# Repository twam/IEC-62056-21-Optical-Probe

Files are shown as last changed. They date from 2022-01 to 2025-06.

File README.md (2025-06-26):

IEC-62056-21-Optical-Probe
===

Optical probe for reading out power meters supporting the [IEC 62056-21](https://www.ungelesen.net/protagWork/media/downloads/solar-steuerung/iec62056-21%7Bed1.0%7Den_.pdf) standard via USB.

Infrared part is based on https://wiki.volkszaehler.org/hardware/controllers/ir-schreib-lesekopf-ttl-ausgang.

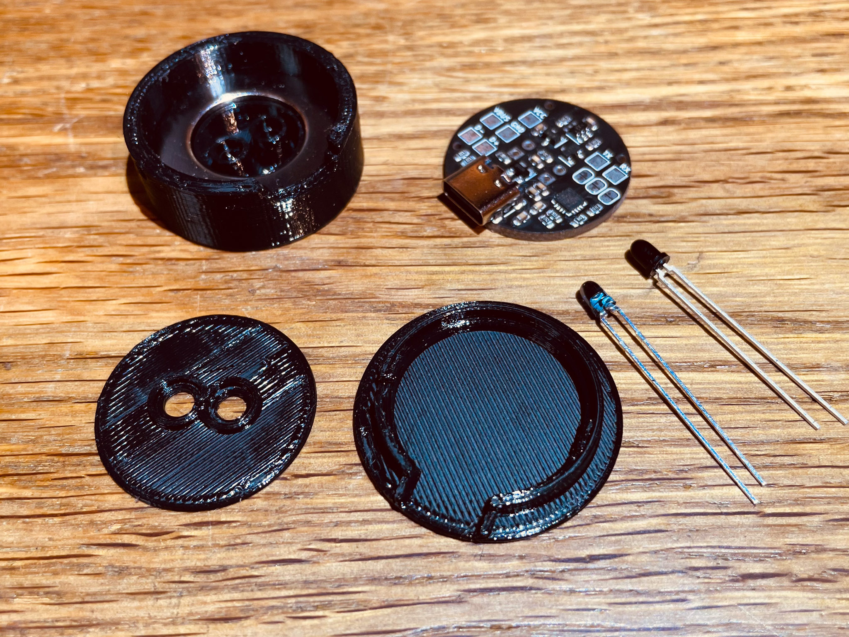
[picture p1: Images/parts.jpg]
PCB and case parts


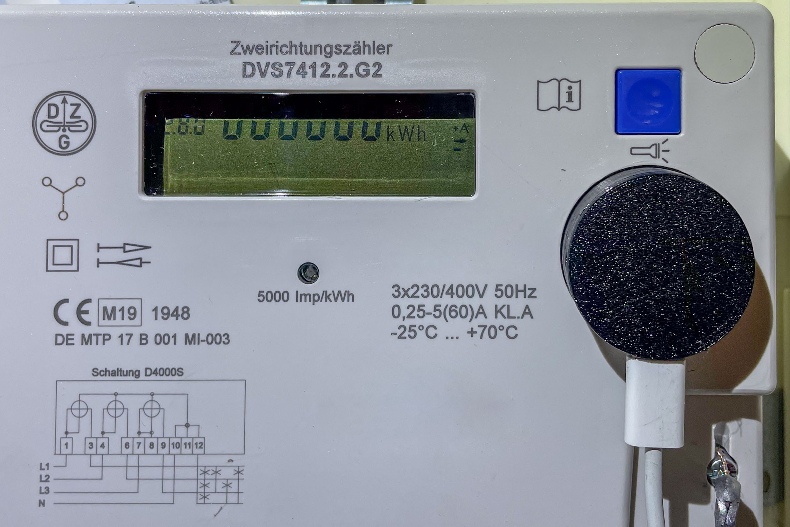
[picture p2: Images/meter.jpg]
Probe mounted on a meter


For the case a ring magnet with Ø 26,75/16 mm and 5 mm height is required, e.g. [this one](https://www.supermagnete.de/eng/ring-magnets-neodymium/ring-magnet-26.75mm-16mm-5mm_R-27-16-05-N).

### JLCPCB

PCBs can be ordered fully-assembled (besides the IR-LED and Photodiode) from [JLCPCB](https://jlcpcb.com/DDE). Required files are
[IEC-62056-21-Optical-Probe_cpl_jlc.csv](Gerber/IEC-62056-21-Optical-Probe_cpl_jlc.csv), [IEC-62056-21-Optical-Probe_bom_jlc.csv](Gerber/IEC-62056-21-Optical-Probe_bom_jlc.csv) and
[IEC-62056-21-Optical-Probe.zip](IEC-62056-21-Optical-Probe.zip).

## License

[][cc-by-sa]

This work is licensed under a [Creative Commons Attribution-NonCommercial-ShareAlike 4.0 International License][cc-by-sa].

[][cc-by-sa]

[cc-by-sa]: http://creativecommons.org/licenses/by-nc-sa/4.0/
[cc-by-sa-image]: https://licensebuttons.net/l/by-nc-sa/4.0/88x31.png
[cc-by-sa-shield]: https://img.shields.io/badge/License-CC%20BY--NC--SA%204.0-lightgrey.svg

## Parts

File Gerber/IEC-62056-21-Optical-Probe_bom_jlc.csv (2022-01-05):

Comment | Designator | Footprint | LCSC Part #
100n/50V | C1,C2,C3,C5,C6 | C_0603_1608Metric | C14663
4u7/16V | C4,C7 | C_0603_1608Metric | C19666
SP0503BAHT | D1 | SOT-143 | C7074
USB_C_Receptacle_USB2.0 | J1 | USB_C_Receptacle_XKB_U262-16XN-4BVC11 | C165948
S8550 | Q2 | SOT-23 | C105432
S8050 | Q4 | SOT-23 | C2146
5k1 | R1,R2 | R_0603_1608Metric | C23186
24k | R4 | R_0603_1608Metric | C23352
47k | R5 | R_0603_1608Metric | C25819
1k | R7 | R_0603_1608Metric | C21190
10k | R12 | R_0603_1608Metric | C25804
180R | R13 | R_0603_1608Metric | C22828
13k | R14,R15,R16 | R_0603_1608Metric | C22797
CP2102N-Axx-xQFN20 | U2 | SiliconLabs_QFN-20-1EP_3x3mm_P0.5mm_EP1.8x1.8mm | C969913
74LVC2G17 | U3 | SC-74-6_1.5x2.9mm_P0.95mm | C513289

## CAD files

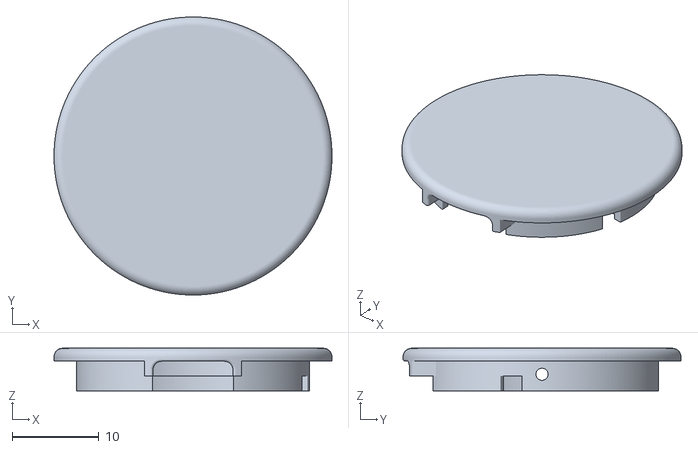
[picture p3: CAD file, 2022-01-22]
Case/Top.stl
32.0 x 32.0 x 4.90

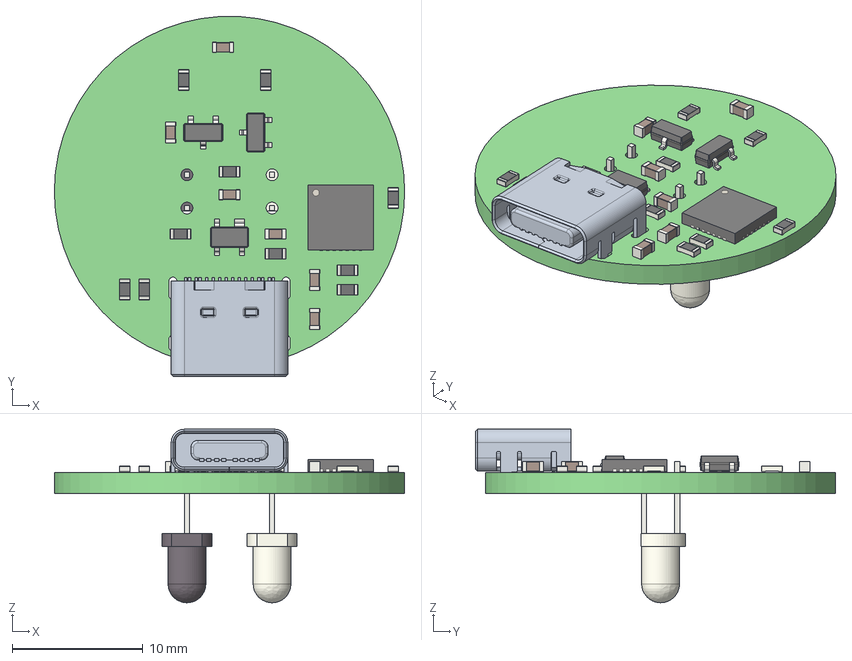
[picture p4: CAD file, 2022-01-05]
IEC-62056-21-Optical-Probe.step
26.8 x 27.5 x 13.3 mm
IEC-62056-21-Optical-Probe PCB

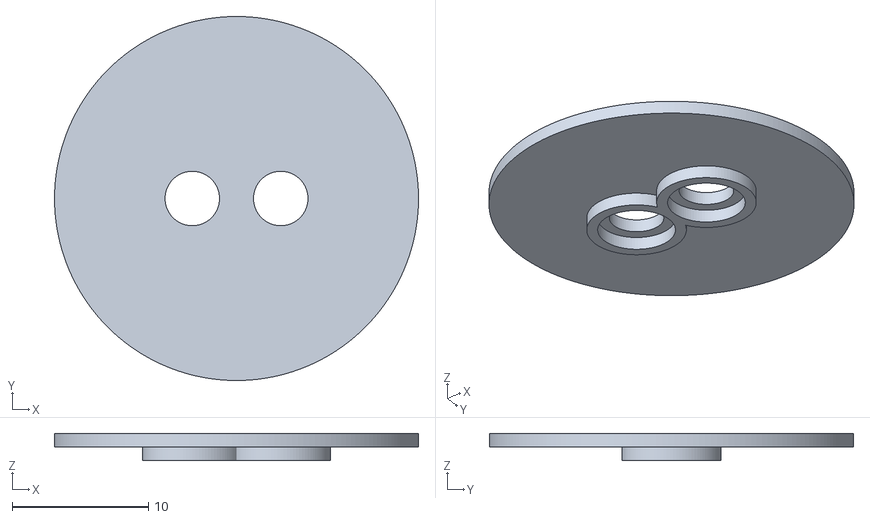
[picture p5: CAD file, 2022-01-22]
Case/Isolation.stl
26.7 x 26.7 x 2.00

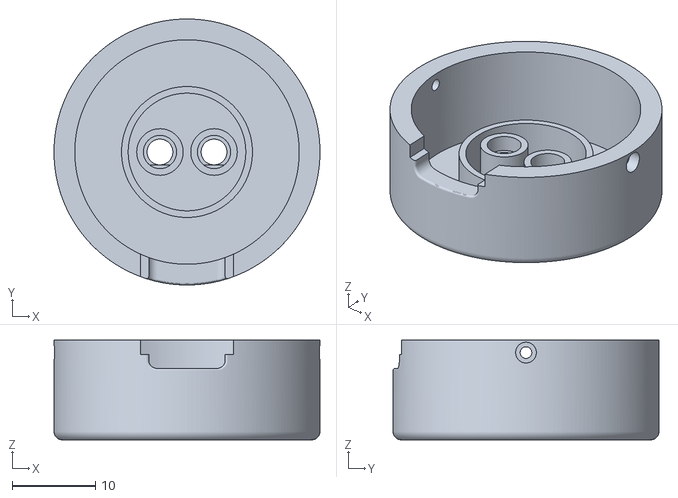
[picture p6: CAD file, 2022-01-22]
Case/Base.stl
32.0 x 32.0 x 12.0

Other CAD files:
Case/Case.f3d

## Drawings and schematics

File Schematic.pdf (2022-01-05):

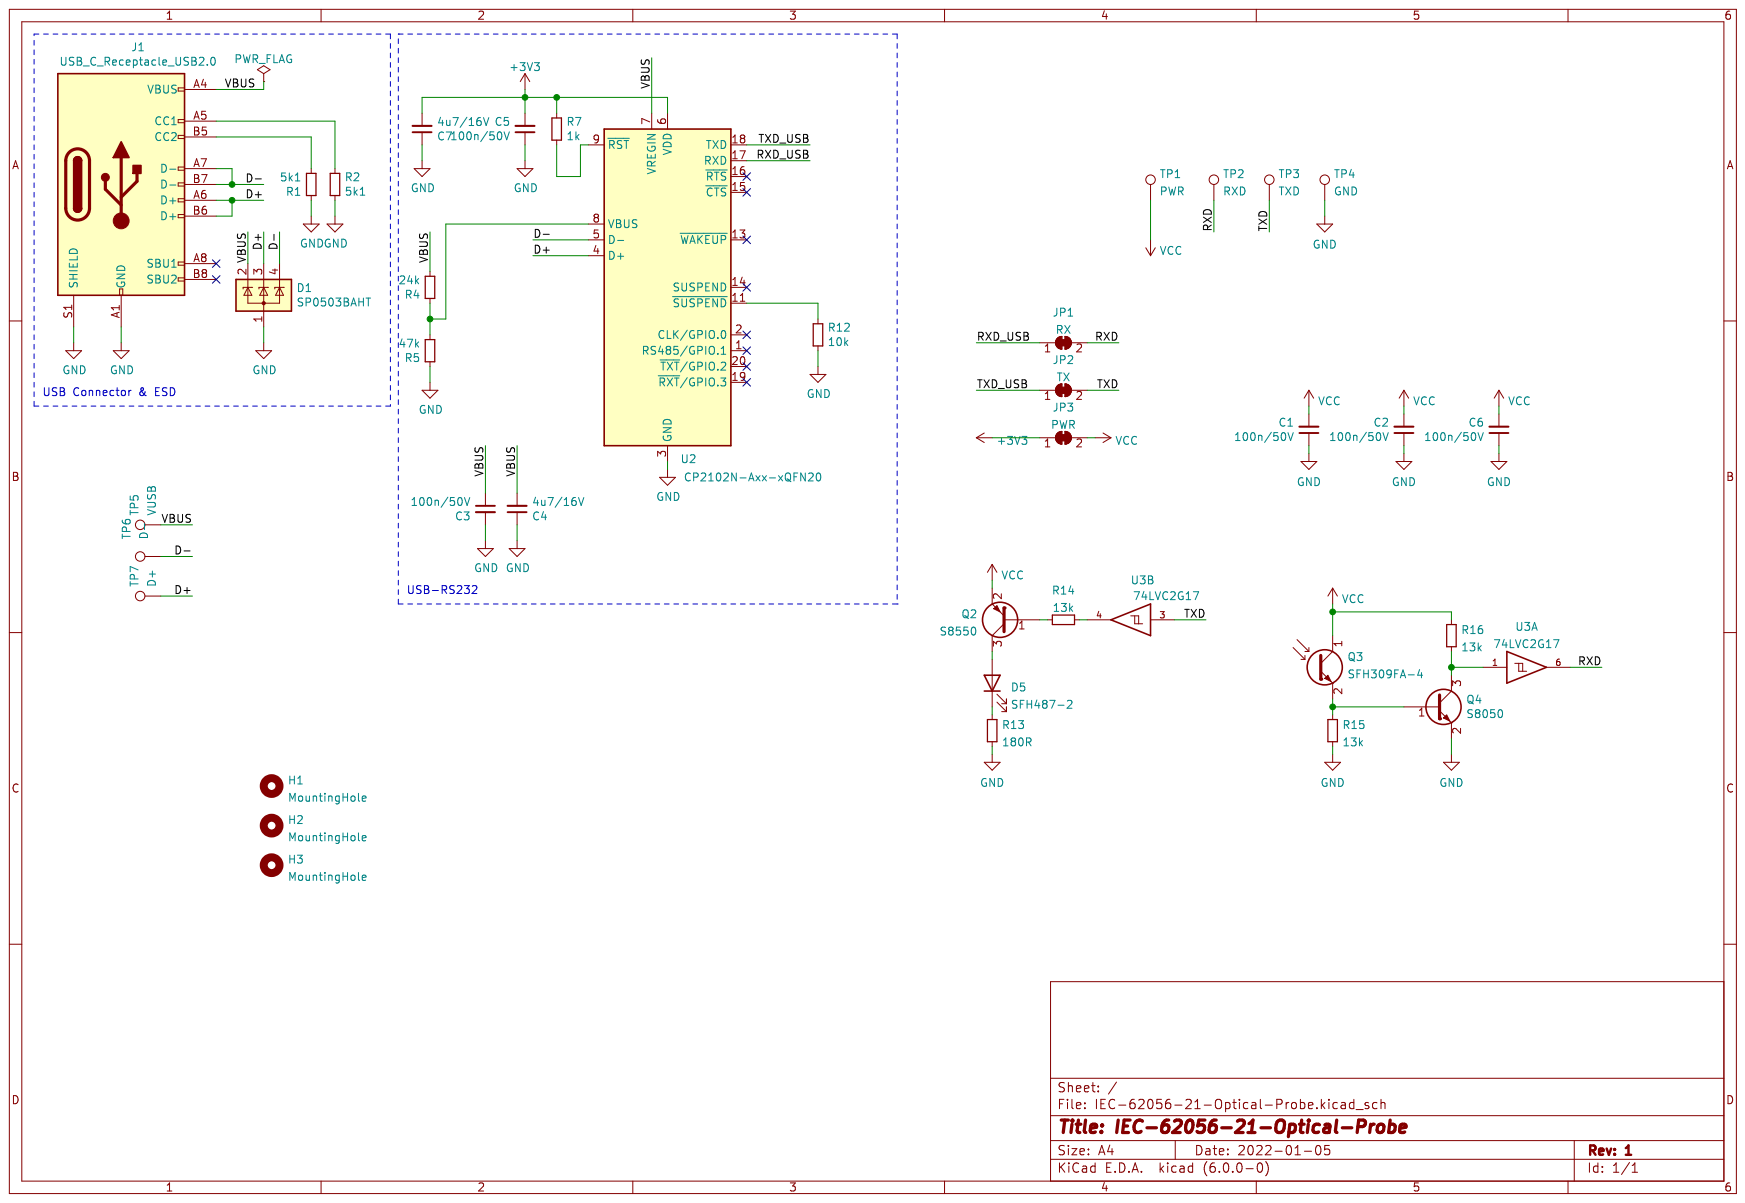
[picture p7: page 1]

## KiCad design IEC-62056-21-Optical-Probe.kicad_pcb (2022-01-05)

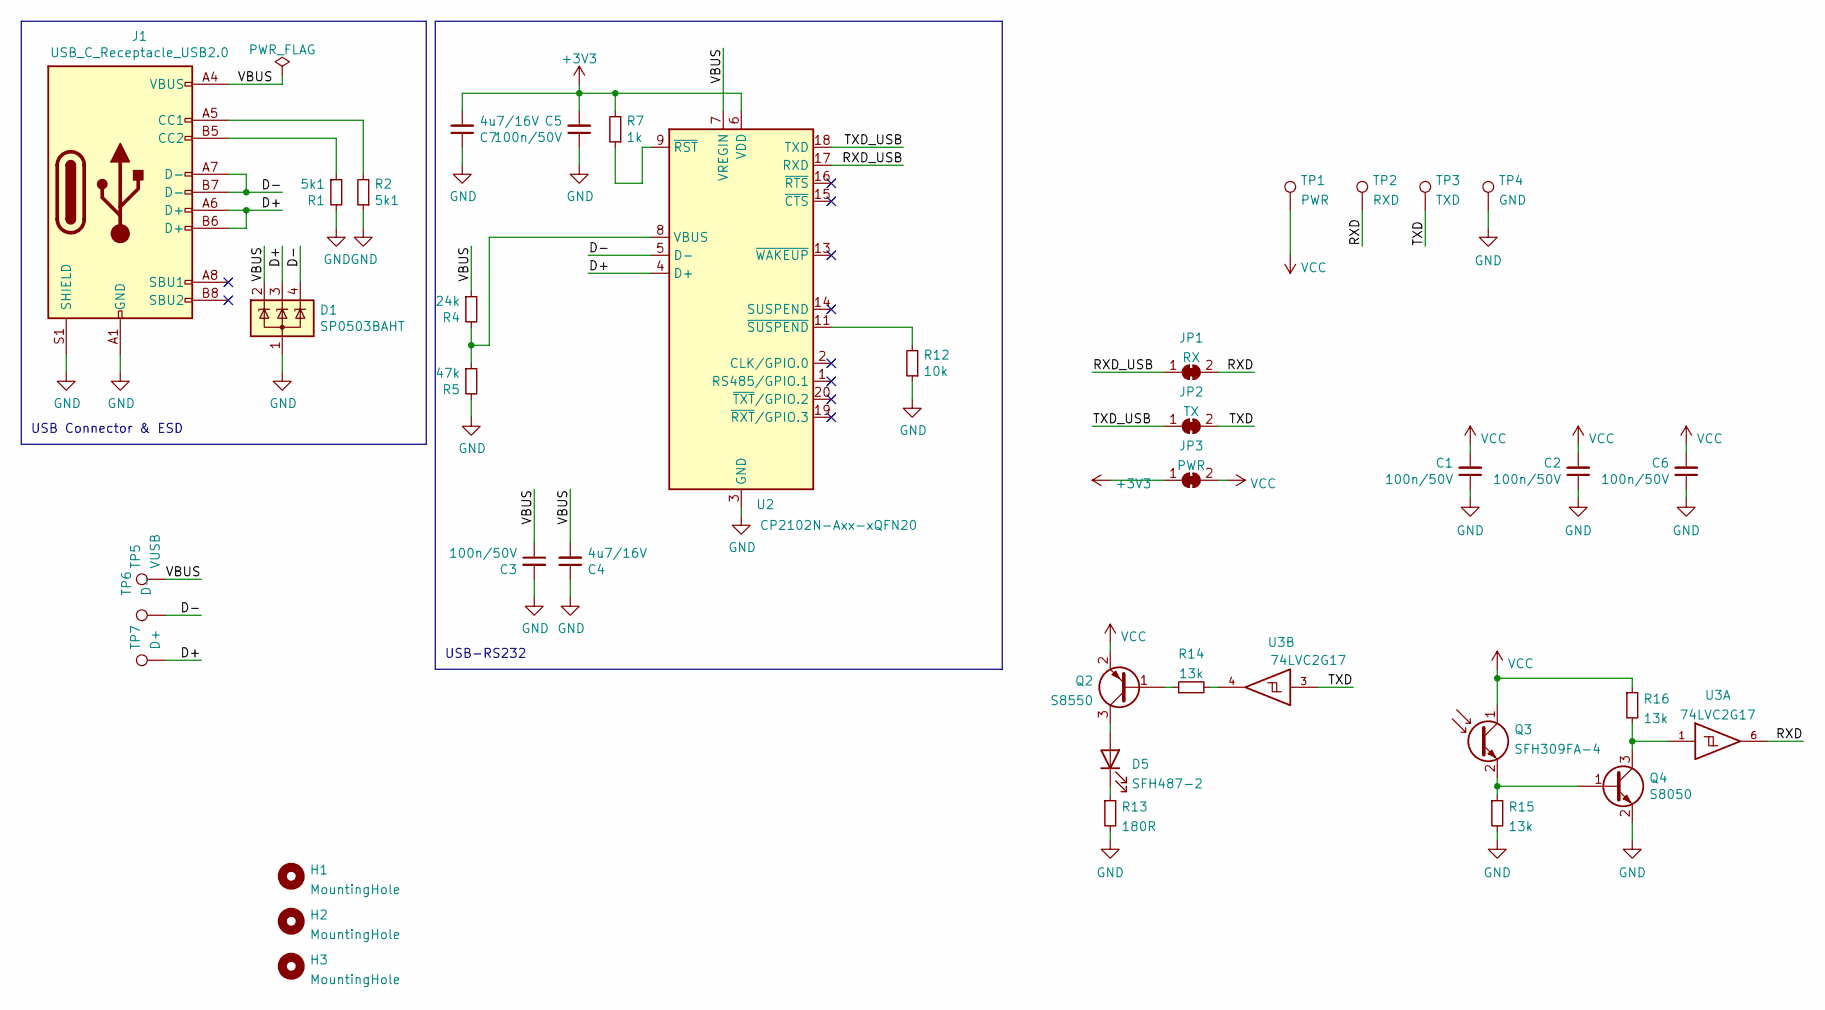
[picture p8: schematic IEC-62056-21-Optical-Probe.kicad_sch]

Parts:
C1, C2, C3, C5, C6: 100n/50V; C_0603_1608Metric; LCSC C14663
C4, C7: 4u7/16V; C_0603_1608Metric; LCSC C19666
D1: SP0503BAHT; SOT-143; LCSC C7074
D5: SFH487-2; LED_D3.0mm_IRBlack
H1, H2, H3: MountingHole; MountingHole_JLCPCB
J1: USB_C_Receptacle_USB2.0; USB_C_Receptacle_XKB_U262-16XN-4BVC11; LCSC C165948
JP1: RX; SolderJumper-2_P1.3mm_Bridged_RoundedPad1.0x1.5mm
JP2: TX; SolderJumper-2_P1.3mm_Bridged_RoundedPad1.0x1.5mm
JP3: PWR; SolderJumper-2_P1.3mm_Bridged_RoundedPad1.0x1.5mm
Q2: S8550; SOT-23; LCSC C105432
Q3: SFH309FA-4; LED_D3.0mm_Clear
Q4: S8050; SOT-23; LCSC C2146
R1, R2: 5k1; R_0603_1608Metric; LCSC C23186
R4: 24k; R_0603_1608Metric; LCSC C23352
R5: 47k; R_0603_1608Metric; LCSC C25819
R7: 1k; R_0603_1608Metric; LCSC C21190
R12: 10k; R_0603_1608Metric; LCSC C25804
R13: 180R; R_0603_1608Metric; LCSC C22828
R14, R15, R16: 13k; R_0603_1608Metric; LCSC C22797
TP1: PWR; TestPoint_Pad_2.0x2.0mm
TP2: RXD; TestPoint_Pad_2.0x2.0mm
TP3: TXD; TestPoint_Pad_2.0x2.0mm
TP4: GND; TestPoint_Pad_2.0x2.0mm
TP5: VUSB; TestPoint_Pad_2.0x2.0mm
TP6: D-; TestPoint_Pad_2.0x2.0mm
TP7: D+; TestPoint_Pad_2.0x2.0mm
U2: CP2102N-Axx-xQFN20; SiliconLabs_QFN-20-1EP_3x3mm_P0.5mm_EP1.8x1.8mm; LCSC C969913
U3: 74LVC2G17; SC-74-6_1.5x2.9mm_P0.95mm; LCSC C513289

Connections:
+3V3: C5.2, C7.2, JP3.1 (A), R7.2, U2.6 (VDD)
/D+: D1.3 (K), J1.A6 (D+), J1.B6 (D+), TP7.1, U2.4 (D+)
/D-: D1.4 (K), J1.A7 (D-), J1.B7 (D-), TP6.1, U2.5 (D-)
/RXD: JP1.2 (B), TP2.1, U3.6
/RXD_USB: JP1.1 (A), U2.17 (RXD)
/TXD: JP2.2 (B), TP3.1, U3.3
/TXD_USB: JP2.1 (A), U2.18 (TXD)
/VBUS: C3.1, C4.2, D1.2 (K), J1.A4 (VBUS), J1.A9 (VBUS), J1.B4 (VBUS), J1.B9 (VBUS), R4.1, TP5.1, U2.7 (VREGIN)
GND: C1.1, C2.1, C3.2, C4.1, C5.1, C6.1, C7.1, D1.1 (A), J1.A1 (GND), J1.A12 (GND), J1.B1 (GND), J1.B12 (GND), J1.S1 (SHIELD), Q4.2 (E), R1.2, R2.1, R5.2, R12.1, R13.2, R15.2, TP4.1, U2.3 (GND), U2.12 (GND), U2.21 (GND), U3.2 (GND)
unnamed: D5.1 (K), R13.1
unnamed: D5.2 (A), Q2.3 (C)
unnamed: J1.A5 (CC1), R2.2
unnamed: J1.B5 (CC2), R1.1
unnamed: Q2.1 (B), R14.1
unnamed: Q3.2 (E), Q4.1 (B), R15.1
unnamed: Q4.3 (C), R16.2, U3.1
unnamed: R4.2, R5.1, U2.8 (VBUS)
unnamed: R7.1, U2.9 (~RST)
unnamed: R12.2, U2.11 (~SUSPEND)
unnamed: R14.2, U3.4
VCC: C1.2, C2.2, C6.2, JP3.2 (B), Q2.2 (E), Q3.1 (C), R16.1, TP1.1, U3.5 (VCC)

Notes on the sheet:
USB Connector & ESD
USB-RS232

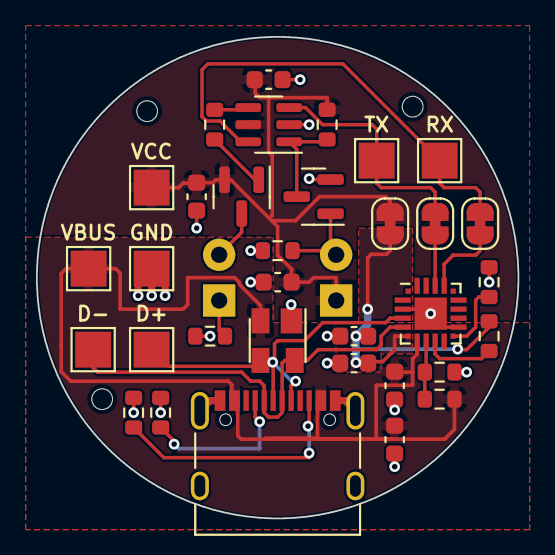
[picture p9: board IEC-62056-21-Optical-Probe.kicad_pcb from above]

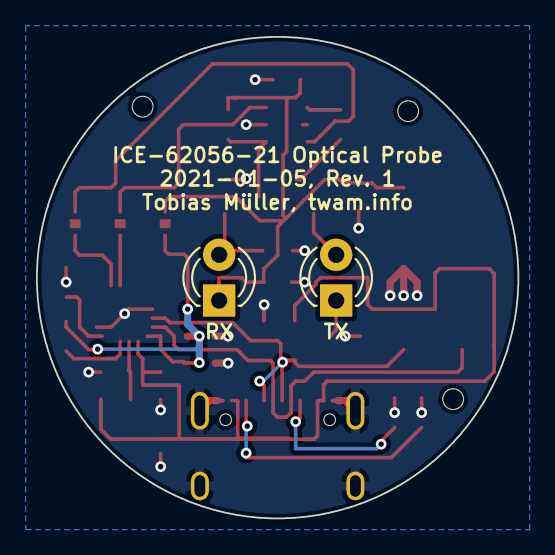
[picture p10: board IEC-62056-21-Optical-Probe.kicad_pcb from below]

Board: 2 copper layers, 26.8 x 26.8 mm, 38 parts (2 on the bottom side), 21 nets.

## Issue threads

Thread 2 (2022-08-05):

Read data address with arduino

KJPOUNDY132, 2022-08-05:
Hi how can i read data from adress with arduino

twam, 2022-08-06:
The probe by default (if you don’t modify anything) has an USB (client) port, so you need a device with an USB host port, such as a PC to talk to it. I‘m not aware of any Arduino support for USB host functionality.

If you don’t populate the USB chip you can connect the RS232 wires to almost any Arduino. RS232 settings then depend on the sensor you want to read out.

KJPOUNDY132, 2022-08-07:
do u have any code for read iec62056 data with arduino

twam, 2022-08-07:
Unfortunately not :(.

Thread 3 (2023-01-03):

Missing base current limiting resistor for Q4

rastikw, 2023-01-03:
When Q3 is open this component is the only thing to limit base current of Q4. With enough IR light this can be in tens of mA. I suggest adding a resistor.

twam, 2023-01-07:
Thanks for the hint! I'll take care of it, when doing a new revision!

GhostDog98, 2025-06-12:
This has not been added from my eye, should I upload a photo of the appropiate bodge that needs to be done?

twam, 2025-06-12:
Yes, please.

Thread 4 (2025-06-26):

Design files for 3D printed probe files

GhostDog98, 2025-06-26:
I'm attempting to design an adapter for my slightly different energy meter port as it isn't round. Is there any chance you could add the design files for the STLs so I can use them as a reference?

twam, 2025-06-26:
Sure: https://github.com/twam/IEC-62056-21-Optical-Probe/blob/master/Case/Case.f3d

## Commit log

2022-01-05 Initial revision
    [IEC-62056-21-Optical-Probe-B_Cu.gbr, IEC-62056-21-Optical-Probe-B_Mask.gbr, IEC-62056-21-Optical-Probe-B_Paste.gbr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]
2022-01-07 Move JLCPCB files to Gerber
    [IEC-62056-21-Optical-Probe_bom_jlc.csv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]
2022-01-22 Add Case
    [Base.stl, Isolation.stl, Top.stl]
2025-06-26 Add F3D version of case
    [Case.f3d]
2025-06-26 Add information about ring magnet
